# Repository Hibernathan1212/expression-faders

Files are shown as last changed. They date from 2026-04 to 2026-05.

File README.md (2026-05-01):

# Expression Faders

A simple midi controller with 2 faders and 2 rotary encoders. This was made for adding midi cc1 and cc11 while playing midi instruments such as strings to give more dynamic range and expression. The rotary encoders can also be mapped to any track specific features such as volume or other daw macros.

The goal was to be able to add more dynamic control while playing on a midi keyboard. Inspired by [Christian Henson](https://youtu.be/O5ax1lMdYO0?si=J35fgkykRBnHvoFT&t=346) and his approach to string writing and playing on a midi keyboard.

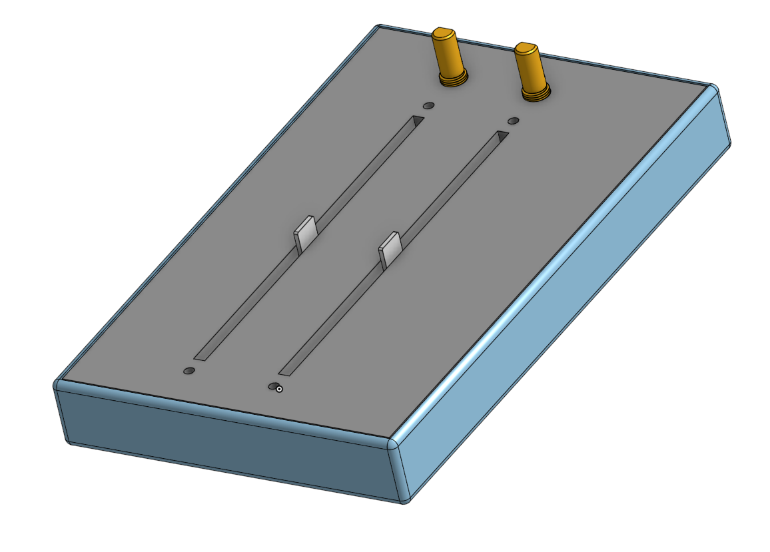
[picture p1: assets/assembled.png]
assembled


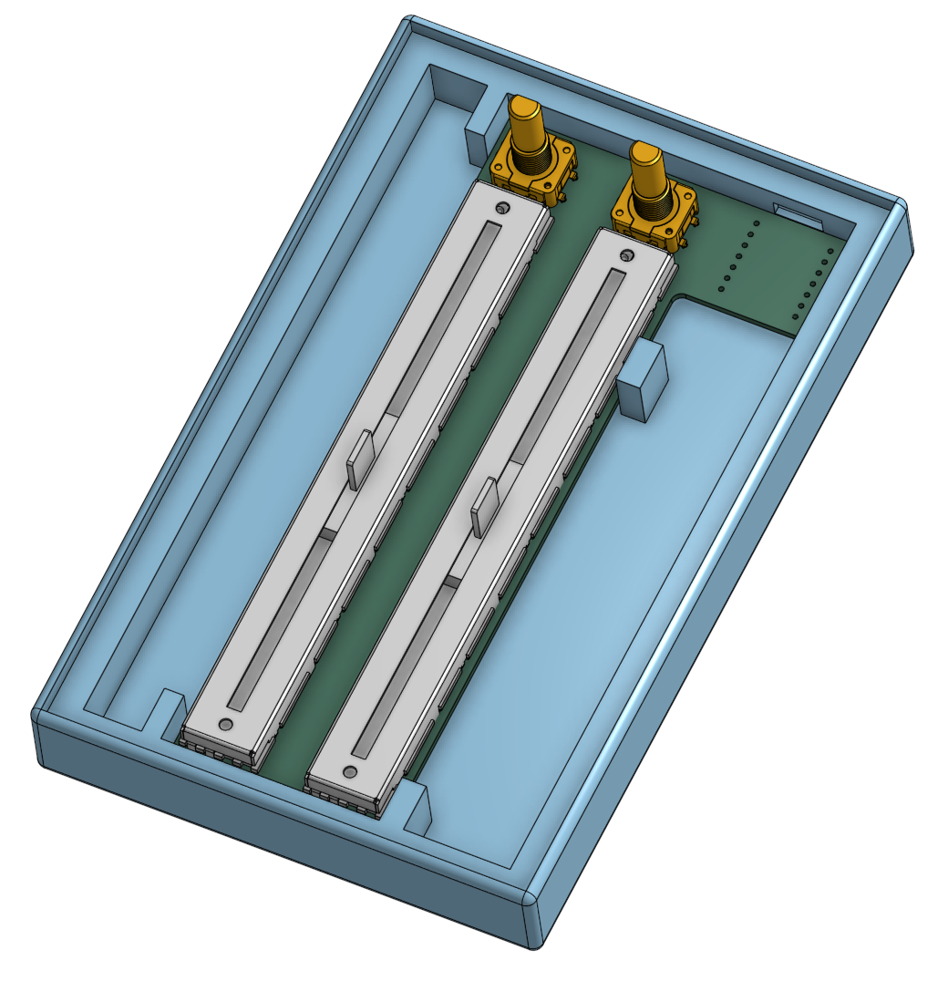
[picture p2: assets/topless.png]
topless


## Features

- 2 ptb0143 100mm faders for controlling midi cc
- 2 ec11 rotary encoders for controlling other daw values such as volume
- Xiao rp2040 for its midi support and size
- Has multiple decoupling caps to ground to reduce electronic noise from signal

## CAD

Consists of a base and a top lid that slots in a lip on the base. PCB is mounted to the lid with 4 m3 screws that go into the faders.

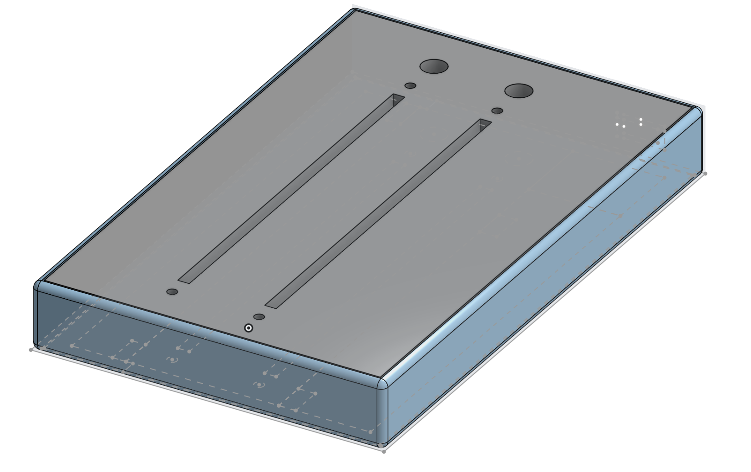
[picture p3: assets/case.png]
case


Made in Onshape.

[source](https://cad.onshape.com/documents/7d573544174621b2e2808d4e/w/58510c4aadba22e801dceb47/e/146ecd20f6130f1f9171a54c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)

## PCB

Made in Kicad.

### Schematic

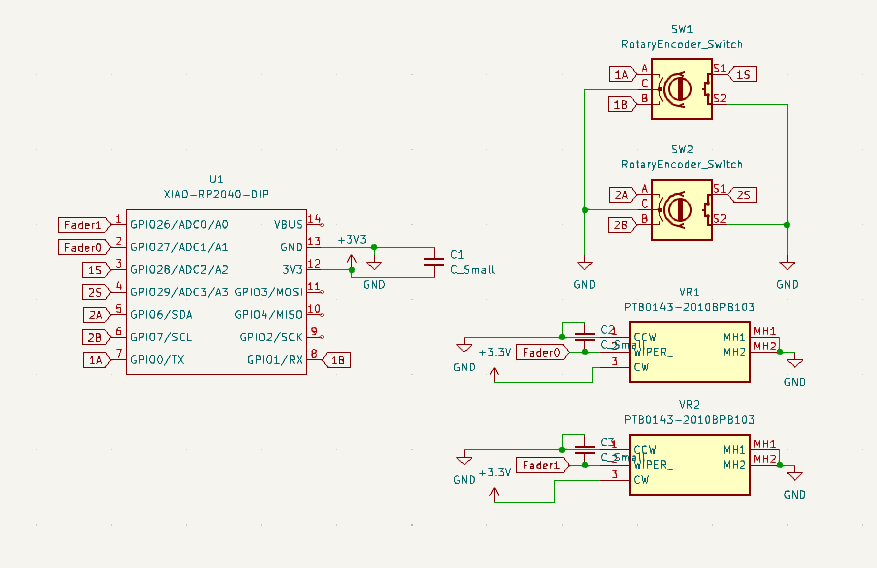
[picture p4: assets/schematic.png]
schematic


### PCB

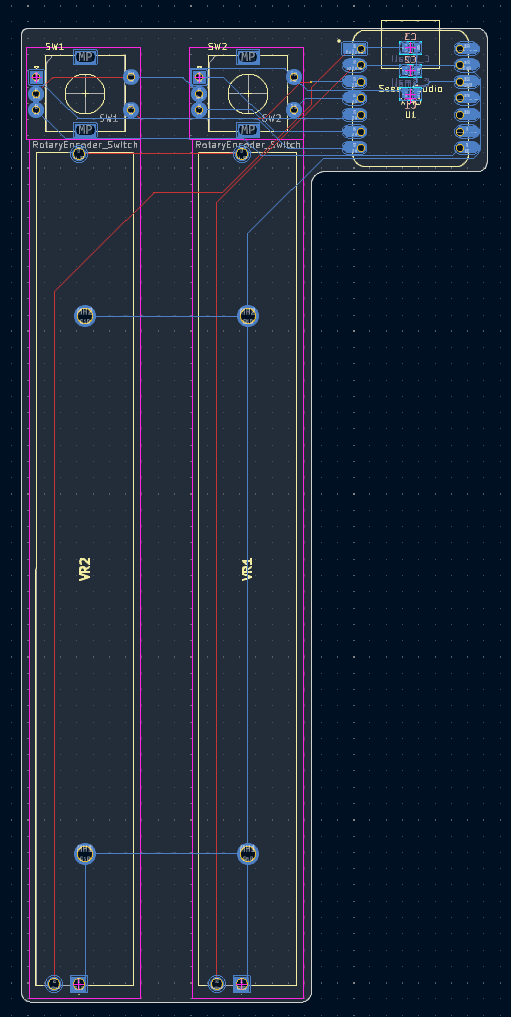
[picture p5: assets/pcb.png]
pcb


## Firmware

Uses python with the usb midi library and adafruit to take the GPIO input and send midi signals back to the computer. Has a hysteresis threshold to try and reduce electronic noise.

## BOM

| Product | Amount | Unit Cost (THB) | Price (THB) | Price (USD) | Link |
| --- | --- | --- | --- | --- | --- |
| EC11 | 2 | 81.42 | 162.84 | 5.00 | [https://th.element14.com/alps/ec11k1524402/encoder-vertical-11mm-30det-15ppr/dp/2064998](https://th.element14.com/alps/ec11k1524402/encoder-vertical-11mm-30det-15ppr/dp/2064998) |
| ptb0143 | 2 | 178.46 | 356.92 | 10.97 | [https://th.element14.com/bourns/ptb0143-2010bpb103/potentiometer-slide-10k-100mm/dp/1688409](https://th.element14.com/bourns/ptb0143-2010bpb103/potentiometer-slide-10k-100mm/dp/1688409) |
| orpheus pico | 1 | ? | ? | 0.00 | |
| m3 screws | 4 | | 132 | 4.06 | [https://th.element14.com/tr-fastenings/m35-bh10mcs100/screw-socket-butt-m3x5-pk100/dp/1420682](https://th.element14.com/tr-fastenings/m35-bh10mcs100/screw-socket-butt-m3x5-pk100/dp/1420682) |
| 100nf 0805 smd capacitors | 10 | 0.43 | 4.3 | 0.13 | [](https://th.element14.com/multicomp-pro/mc0805b104k250ct/cap-0-1-f-25v-10-x7r-0805/dp/1759166)[https://th.element14.com/multicomp-pro/mc0805b104k250ct/cap-0-1-f-25v-10-x7r-0805/dp/1759166](https://th.element14.com/multicomp-pro/mc0805b104k250ct/cap-0-1-f-25v-10-x7r-0805/dp/1759166) |
| element 14 shipping | | | 550 | 16.90 | |
| jlcpcb | | | | 12.13 | |
| | | | | | |
| total | | | | 49.18 | |

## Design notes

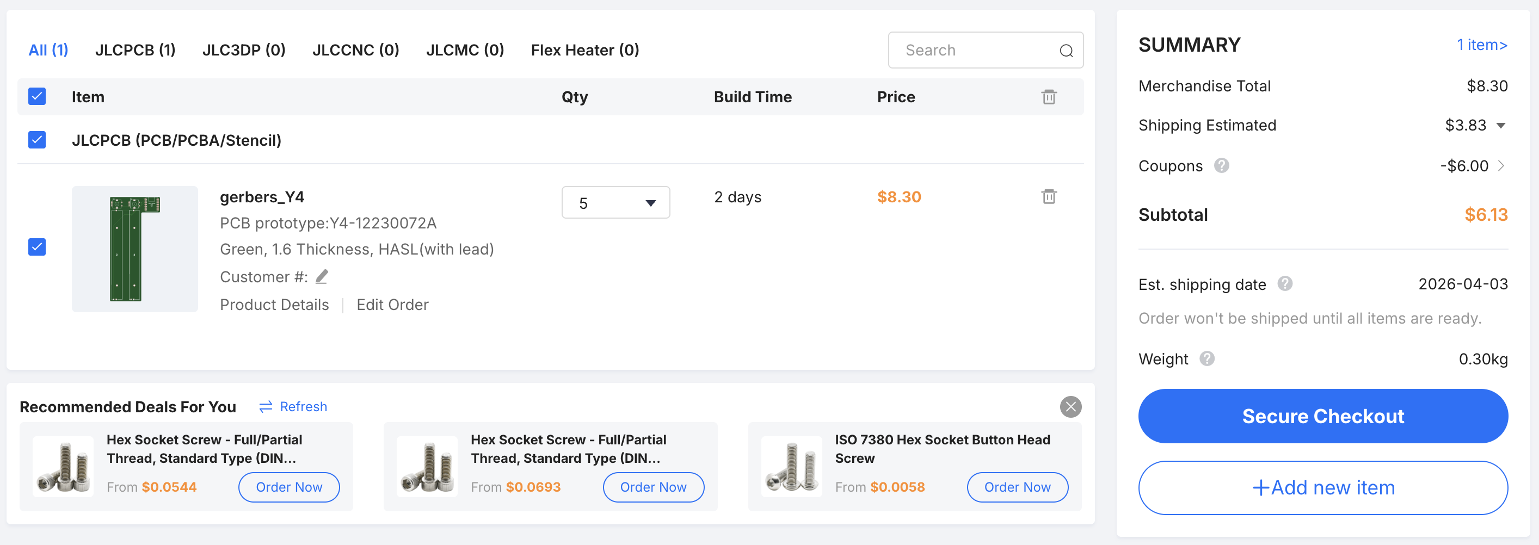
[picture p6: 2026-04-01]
assets/Screenshot 2026-04-01 at 9.42.38 AM.png

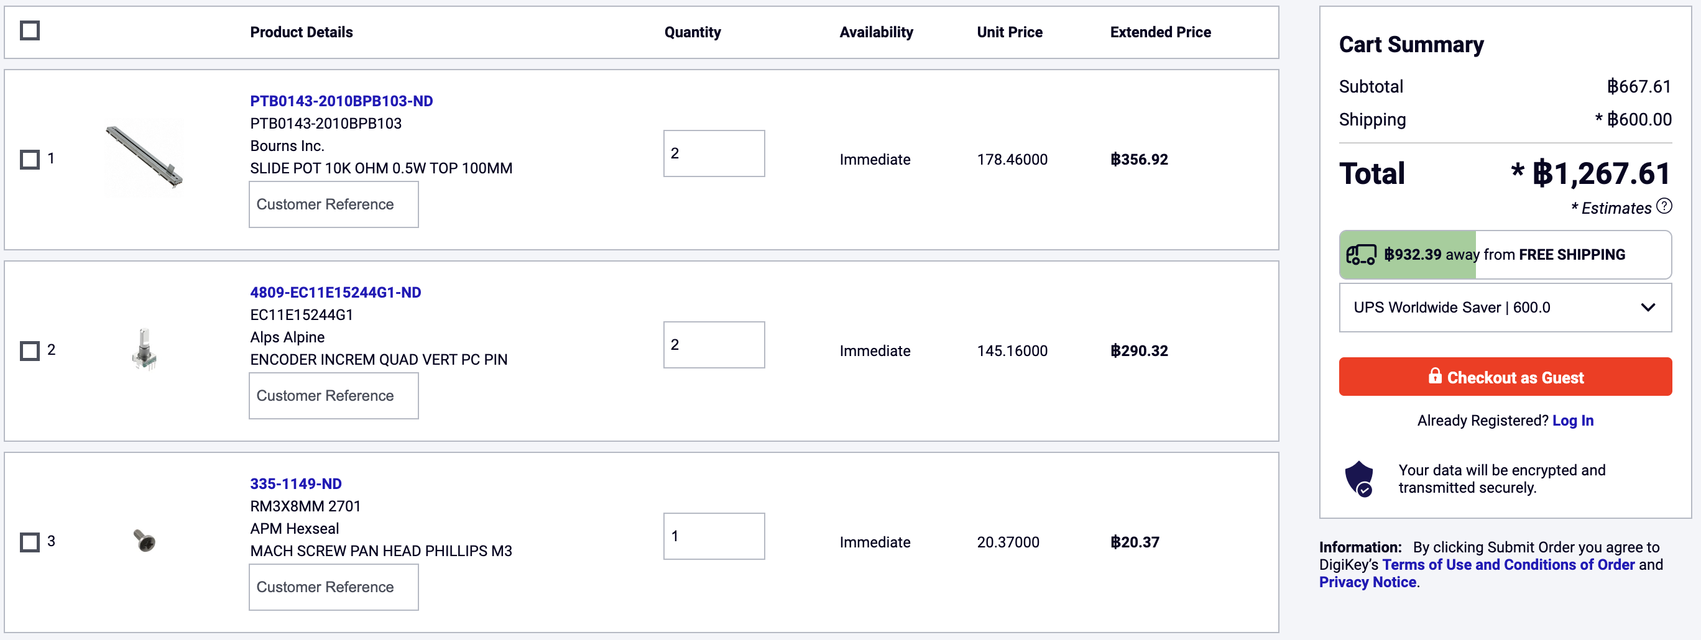
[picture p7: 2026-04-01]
assets/Screenshot 2026-04-01 at 9.45.49 AM.png

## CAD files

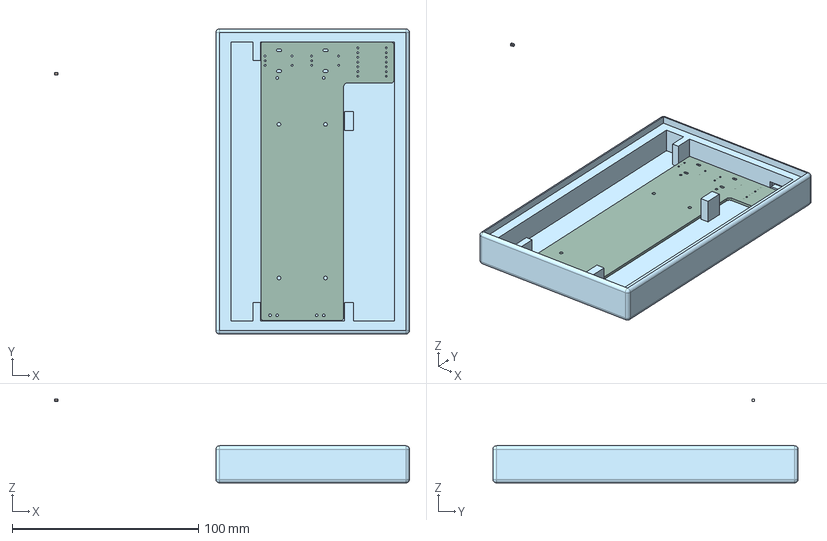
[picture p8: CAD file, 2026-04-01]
cad/Assembly.step
190.7 x 164.0 x 45.1 mm
C_0805_2012Metric
expression faders_PCB

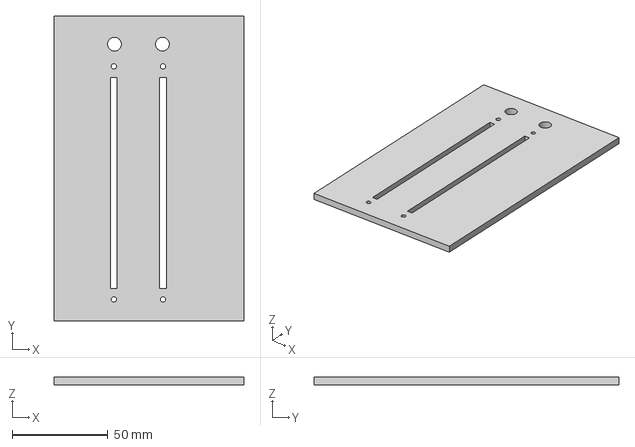
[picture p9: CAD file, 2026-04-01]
cad/top.step
99.0 x 159.0 x 4.00 mm

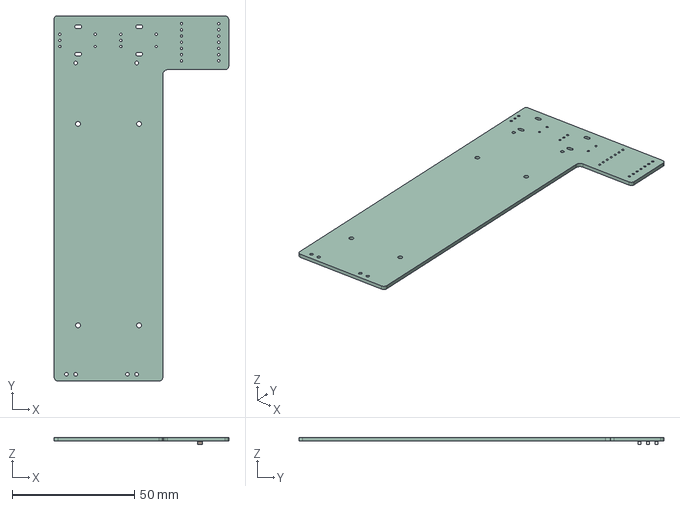
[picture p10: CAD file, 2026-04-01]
pcb/pcb.step
71.5 x 149.5 x 2.84 mm
C_0805_2012Metric x 3
expression faders_PCB

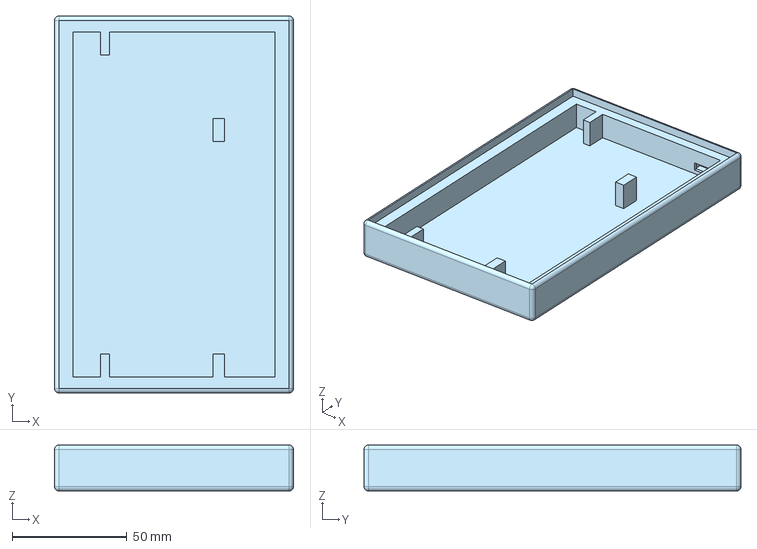
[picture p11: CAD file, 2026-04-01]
production/base.step
104.0 x 164.0 x 20.0 mm

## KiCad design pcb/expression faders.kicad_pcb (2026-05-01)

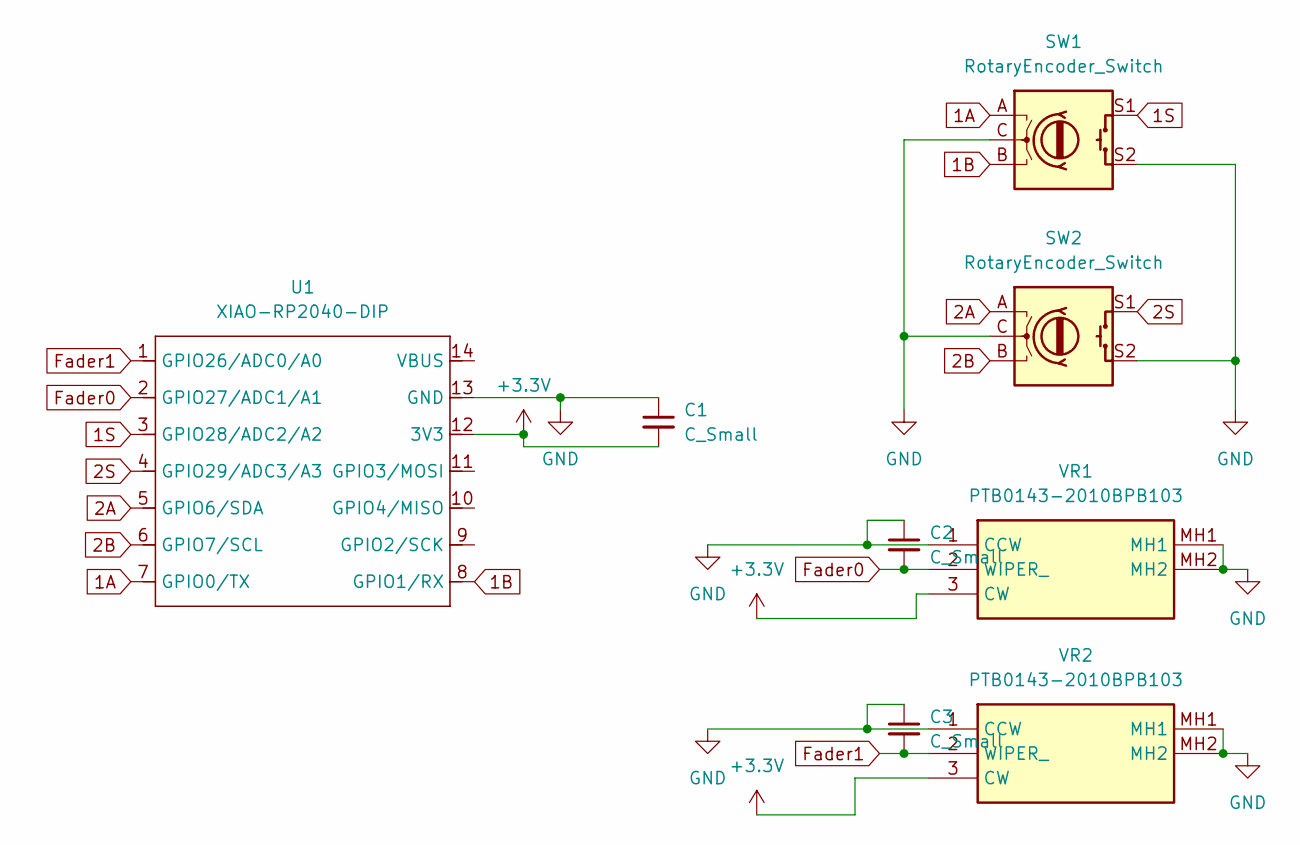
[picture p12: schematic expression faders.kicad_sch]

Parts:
C1, C2, C3: C_Small; C_0805_2012Metric
SW1, SW2: RotaryEncoder_Switch; RotaryEncoder_Alps_EC11E-Switch_Vertical_H20mm
U1: XIAO-RP2040-DIP; XIAO-Generic-Hybrid-14P-2.54-21X17.8MM
VR1, VR2: PTB0143-2010BPB103; PTB01432010BPB103; Manufacturer_Part_Number PTB0143-2010BPB103; Mouser Part Number 652-PTB1432010BPB103

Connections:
1A: SW1.A, U1.7 (GPIO0/TX)
1B: SW1.B, U1.8 (GPIO1/RX)
1S: SW1.S1, U1.3 (GPIO28/ADC2/A2)
2A: SW2.A, U1.5 (GPIO6/SDA)
2B: SW2.B, U1.6 (GPIO7/SCL)
2S: SW2.S1, U1.4 (GPIO29/ADC3/A3)
+3.3V: C1.2, U1.12 (3V3), VR1.3 (CW), VR2.3 (CW)
Fader0: C2.2, U1.2 (GPIO27/ADC1/A1), VR1.2 (WIPER_)
Fader1: C3.2, U1.1 (GPIO26/ADC0/A0), VR2.2 (WIPER_)
GND: C1.1, C2.1, C3.1, SW1.C, SW1.S2, SW2.C, SW2.S2, U1.13 (GND), VR1.1 (CCW), VR1.MH1, VR1.MH2, VR2.1 (CCW), VR2.MH1, VR2.MH2

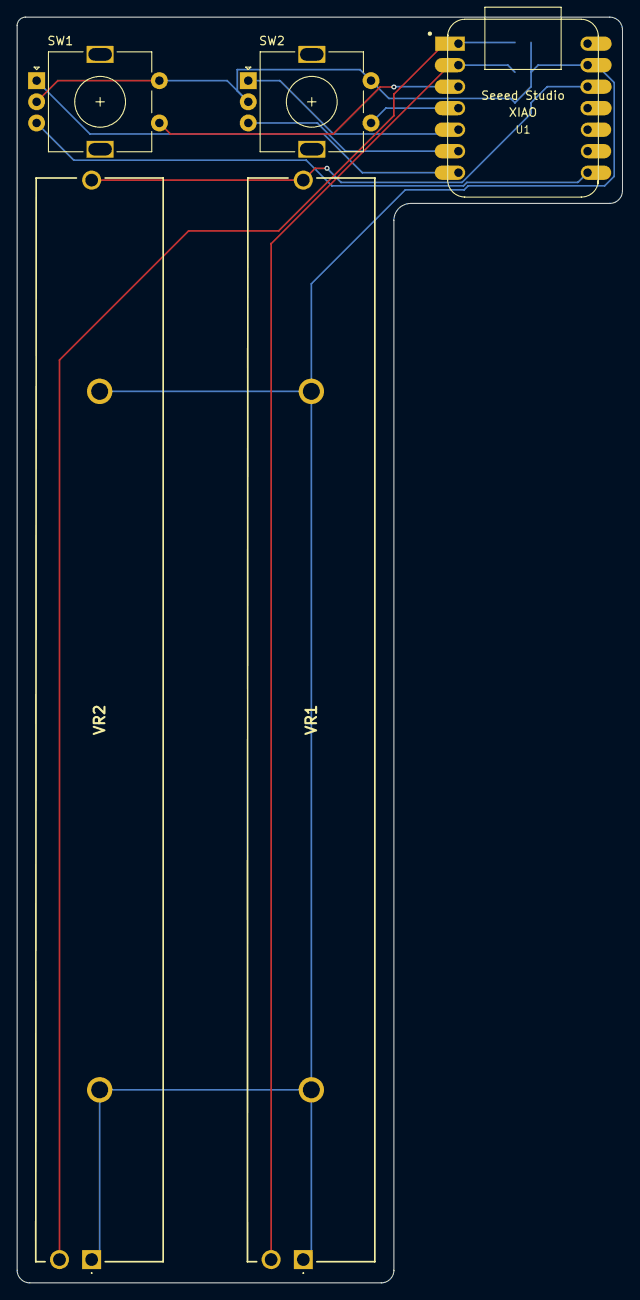
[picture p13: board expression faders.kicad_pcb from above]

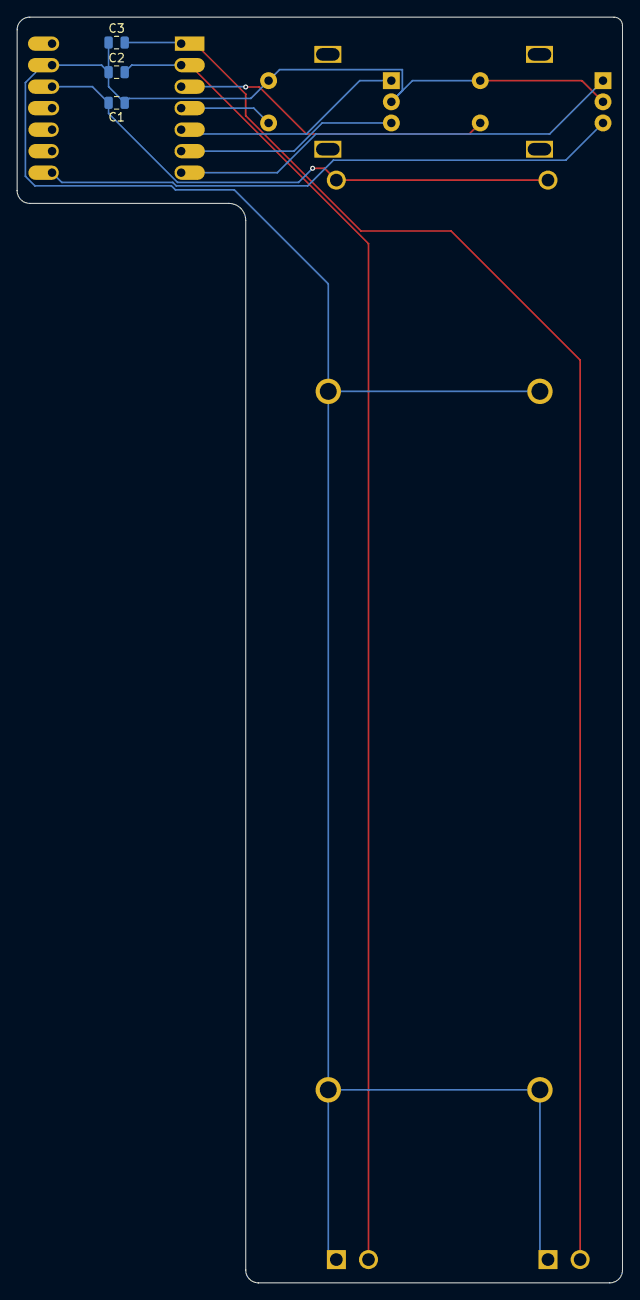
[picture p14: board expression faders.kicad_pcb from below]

Board: 2 copper layers, 71.5 x 149.5 mm, 8 parts (3 on the bottom side), 10 nets.

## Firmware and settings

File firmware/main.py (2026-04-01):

import board
import analogio
import rotaryio
import digitalio
import usb_midi
import adafruit_midi
from adafruit_midi.control_change import ControlChange

CC_FADER0 = 11  # Expression
CC_FADER1 = 1  # Modulation
CC_ENC1 = 20
CC_ENC2 = 21

midi = adafruit_midi.MIDI(midi_out=usb_midi.ports[1], out_channel=0)

fader0 = analogio.AnalogIn(board.GP27)
fader1 = analogio.AnalogIn(board.GP26)

enc1 = rotaryio.IncrementalEncoder(board.GP01, board.GP00)
enc2 = rotaryio.IncrementalEncoder(board.GP07, board.GP06)

last_fader0_val = 0
last_fader1_val = 0
last_enc1_pos = 0
last_enc2_pos = 0


def get_midi_val(analog_in):
    return analog_in.value >> 9


while True:
    current_f0 = get_midi_val(fader0)
    if abs(current_f0 - last_fader0_val) > 1:  # Hysteresis threshold
        midi.send(ControlChange(CC_FADER0, current_f0))
        last_fader0_val = current_f0

    current_f1 = get_midi_val(fader1)
    if abs(current_f1 - last_fader1_val) > 1:
        midi.send(ControlChange(CC_FADER1, current_f1))
        last_fader1_val = current_f1

    curr_enc1_pos = enc1.position
    if curr_enc1_pos != last_enc1_pos:
        direction = 127 if curr_enc1_pos < last_enc1_pos else 1
        midi.send(ControlChange(CC_ENC1, direction))
        last_enc1_pos = curr_enc1_pos

    curr_enc2_pos = enc2.position
    if curr_enc2_pos != last_enc2_pos:
        direction = 127 if curr_enc2_pos < last_enc2_pos else 1
        midi.send(ControlChange(CC_ENC2, direction))
        last_enc2_pos = curr_enc2_pos
